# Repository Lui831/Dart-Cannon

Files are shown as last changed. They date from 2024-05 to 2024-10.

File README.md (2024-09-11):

# *Dart Cannon*

### **Integrantes da Equipe**

- João Vitor Choueri Branco (21.01075-7);
- Luiz Henrique Antoniassi Santos (21.01392-6);
- Pedro Afonso Wirthmann Dian (21.01335-7);
- Vitor Guirão Soller (21.01444-2);

---

### **Descrição do Projeto**

O projeto anual envolveu o desenvolvimento do Dart Cannon, um canhão lançador de projéteis leves com um único grau de liberdade, permitindo o disparo em um plano predefinido, e a integração de um sistema inteligente baseado em uma Raspberry Pi. Equipado com uma WebCam para reconhecimento facial, o sistema identifica rostos registrados e aciona o canhão apenas quando uma correspondência é encontrada. Complementando a automação, um dashboard online foi criado usando a plataforma Ubidots, oferecendo controle remoto do ângulo do Dart Cannon, monitoramento do último rosto identificado e um gatilho virtual para o disparo, proporcionando uma solução inovadora e interativa para o lançamento de projéteis.

Para acessar cada parte do projeto (dividido em semestres), acesse as pastas [Semestre1](https://github.com/Lui831/Dart-Cannon/tree/main/Semestre1) e [Semestre2](https://github.com/Lui831/Dart-Cannon/tree/main/Semestre2).

Grupo

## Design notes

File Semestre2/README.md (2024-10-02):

# Dart Cannon v2.0 - Reconhecimento facial

**Dart Cannon** é o projeto do 2° semestre da disciplina **Microcontroladores e Sistemas Embarcados** (EEN251) do **Instituto Mauá de Tecnologia** (IMT), ministrada pelos professores [Sergio Ribeiro Augusto](https://www.linkedin.com/in/sergio-ribeiro-augusto-258a9ba0/?originalSubdomain=br) e [Rodrigo França](https://www.linkedin.com/in/rodrigo-fran%C3%A7a-847872b1/).<br>
Este repositório é responsável pela parte de IoT da aplicação. A infraestrutura AWS foi configurada manualmente

# Requisitos

| id  | requisito | tipo |
| --- | --- | --- |
| 1 | Utilizar sensores digitais | Técnico |
| 2 | Tirar fotos quando reconhecer rostos | Funcional |
| 3 | Subir as fotos em bucket S3 | Funcional |
| 4 | Comparar rostos com as fotos tiradas | Técnico |
| 5 | Utilizar padrões de comunicação HTTP ou MQTT | Técnico |
| 6 | Comunicar-se com outro dispositivo | Técnico |

# Escopo

O projeto consiste em uma Raspberry Pi conectado ao lançador Dart Cannon previamente desenvolvido. O microcomputador possui uma WebCam responsável por reconhecer rostos, então as imagens são comparadas com rostos previamente registrado e caso o resultado seja positivo, o Dart Cannon atira. Também foi construído um dashboard online via Ubidots, no qual ele possui um controlador do ângulo do Dart Cannon, assim como o registro do último rosto identificado pela câmera, e também um gatilho virtual do canhão.

## Diagrama de blocos

Em uma visão do sistema em alto nível, pode-se compreender seu funcionamento a partir do diagrama de blocos visto abaixo.

Dart_Cannon - Blocos

## Esquemático Elétrico

Baseando-se no diagrama de blocos exposto no último tópico e nas tecnologias utilizadas, foi possível a idealização do esquemático elétrico abaixo.

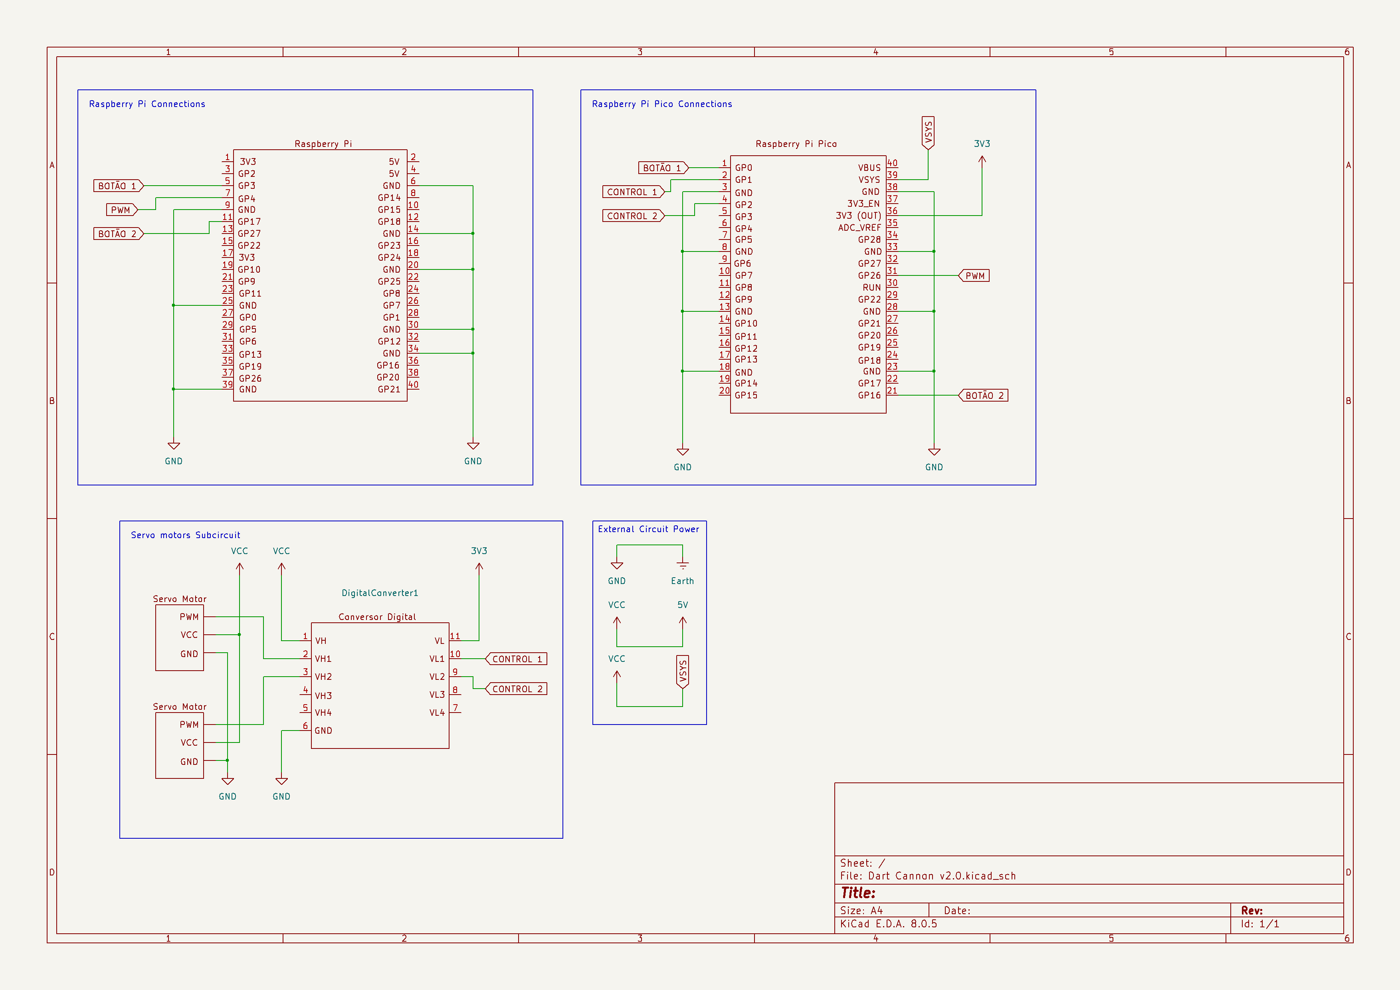
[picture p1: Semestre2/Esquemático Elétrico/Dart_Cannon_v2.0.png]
Dart_Cannon - Blocos


## Tecnologias e conceitos

- AWS
- Requisições HTTP
- Ubidots
- Node-Red
- PIO (Entrada e saída do microprocessador)
- APIs
- Redes

## Materiais

O sistema é montado com os seguintes componentes:

- *Raspberry Pi 3 Model B+* (R$ 385,60);
- *Raspberry* PI Pico (R$ 33,90);
- Servo Motor MG996 (R$ 28,02);
- Servo Motor SG90 (R$ 13,78);
- Filamento PLA para Impressão 3D (R$ 15,00);
    - 100 R$ / filamento de 1 kg, mas o projeto utilizou 150g de filamento
- Mola para acionamento do gatilho (R$ 100,00);
- Placas MDF para base do canhão (R$ 22,00);

Assim, o custo total de implementação do projeto foi de **R$598,30**.

## Modelagem eletrônica

A parte eletrônica do sistema, centralizada essencialmente no Raspberry Pi Pico, foi responsável pelo acionamento de três grandes ações:

- Acionamento manual do canhão, a partir do *dashboard* proveniente do *Ubidots*.
- Acionamento automático do canhão, a partir do reconhecimento visual do ~~REDACTED~~.
- Escolha da angulação do canhão em relação ao eixo do horizonte, com precisão de 9 graus.

Dessa forma, para cada uma das funcionalidades implementadas, os seguintes fluxos de informação foram implementados:

- Para o acionamento manual do canhão, uma estrutura baseada em MQTT foi implementada para a comunicaçao com um botão implementado no *Ubidots*. Essa estrutura foi fundamentada no *Node-RED* e, após realizar a leitura do botão a partir de uma requisição, transfere o seu valor por meio de um sinal digital para o Raspberry Pi Pico, o qual realiza o acionamento do gatilho do canhão.
- Para o acionamento automático do canhão, o funcionamento pode ser considerado análogo ao caso anterior. No entanto, ao invés da determinação do valor de acionamento ser feito a partir da leitura de uma variável no *Ubidots*, esta é realizada por meio do reconhecimento facial (ou não), do ~~REDACTED~~.
- Para a escolha da angulação do canhão, seu funcionamento é também análogo ao seu acionamento manual. No entanto, para a passagem do valor de ângulo do Raspberry Pi para o Raspberry Pi Pico, foi adotada uma transmissão por meio de PWM (o valor do ângulo era linearmente proporcional ao *Duty Cycle* do PWM). Dessa forma, o valor do slider é obtido a partir de uma requisição MQTT por parte do Raspberry Pi a partir do *Node-RED*, dessa forma, este transmite um PWM de valor médio proporcional ao valor do slider, o qual é amostrado pelo Raspberry Pi Pico que efetua a mudança de ângulo do servomotor.

Dessa forma, é possível visualizar as **conexões** realizadas, especialmente entre o Raspberry Pi e Raspberry Pi Pico para a realização das funcionalidades apresentadas, a partir da imagem abaixo.

# Funcionamento

## Funcionamento da Aplicação

**Processo de identificação do rosto**
   - A WebCam fica ativa verificando se existe um rosto detectado;
   - Após 5 segundos, caso ele identifique um rosto novamente, uma foto é tirada e enviada ao _Rekognition_ para validar se tal imagem é parecida o suficiente com o rosto pré-armazenado;
   - Caso o rosto seja parecido, um sinal é enviado ai Raspberry Pi Pico para o disparo do canhão.

**Dashboard Ubidots**
  - Possui um controle deslizante que permite o controle remoto do ângulo do canhão;
  - Possui um botão de disparo do canhão.
  - Possui uma parte referente ao registro da última imagem de rostos reconhecidos pela câmera. Ela é recebida após o upload de uma imagem no _Bucket S3_, a partir de uma _Lambda Function_ acionada como _trigger_ do evento;

## Integração com AWS

arquitetura t3 dart cannon

## Fluxograma do Node-RED Implementado no Raspberry Pi

De forma a complementar o diagrama de blocos exposto anteriormente, é possível especificar as funções e o fluxo de dados para o *Node-RED* a partir da imagem abaixo:

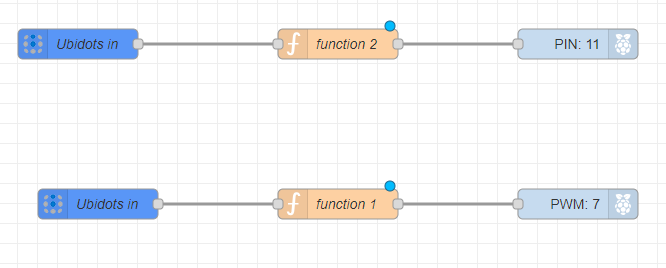
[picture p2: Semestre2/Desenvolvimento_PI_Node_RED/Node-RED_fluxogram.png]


O funcionamento do fluxograma é melhor detalhado na seção anterior, já que é responsável por interfacear diretamente o *dashboard* *Ubidots* e o Raspberry Pi Pico. Para uma melhor compreensão e replicabilidade do fluxograma, é possível obtê-lo diretamente a partir do arquivo `node_red_json.json`, em `./Desenvolvimento_PI_Node_RED`.

## Interface Física a partir do Raspberry Pi Pico

Apresentando seu comportamento descrito na aba "Modelagem Eletrônica", o Raspberry Pi Pico foi responsável por:

- Acionamento do servomotor de "Tiro" a partir do valor digital enviado pelo Raspberry Pi a partir do *Node-RED*.
- Acionamento do servomotor de "Tiro" a partir do valor digital enviado pelo Raspberry Pi a partir do código de reconhecimento facial.
- Controle do ângulo do servomotor de "Angulação" a partir do PWM enviado pelo Raspberry Pi a partir do *Node-RED*.

Para uma melhor visualização de seu funcionamento e operação, é possível encontrar seu código `main.py`, em *Micropython*, na pasta `./Desenvolvimento_PI_Pico`.

# Testes

## Dia 28/08/2024
No dia especificado, fizemos a primeira validação da nossa ideia, utilizando como "cobaia" o professor Sérgio:

https://github.com/user-attachments/assets/659adb91-fa6f-429c-997f-8389b5c48c2b

## Dia 11/09/2024 - Apresentação final

https://github.com/user-attachments/assets/f74fdf56-1614-4386-86fe-6d4188c7c860

## Foto da equipe

Foto da equipe

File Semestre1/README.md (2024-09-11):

# *Dart Cannon v1.0*

### **Descrição Geral**

Repositório para o armazenamento de arquivos, *datasheets*, esquemáticos e códigos referentes ao primeiro projeto semestral da disciplina Microcontroladores e Sistemas Embarcados.

### **Integrantes da Equipe**

- João Vitor Choueri Branco (21.01075-7);
- Luiz Henrique Antoniassi Santos (21.01392-6);
- Pedro Afonso Wirthmann Dian (21.01335-7);
- Vitor Guirão Soller (21.01444-2);

---

### **Descrição do Projeto**

O projeto visa a criação de um canhão lançador de projéteis leves, o *`Dart Cannon`*, o qual teria somente **um** grau de liberdade (atira projéteis somente em um plano pré-determinado) e **calcularia** a trajetória estimada do projeto a ser atirado segundo uma referência específica.

### **Requisitos do Projeto**

Com base em sua descrição simplificada, é possível o levantamento de alguns requisitos necessários para o funcionamento do dispositivo:
1. Desenvolver um canhão capaz de atirar uma bola de ping-pong;
2. Tal canhão deve ter o ângulo em relação ao eixo X controlado pelo usuário;
3. O disparo do canhão deve ser controlado pelo usuário;
4. Deve estimar a altura aproximada da bolinha em relação a um obstáculo a uma distância previamente calculada, exibindo tal valor para o usuário.

### **Lista de Componentes**

- *Raspberry* PI Pico (R$ 33,90);
- Servo Motor MG996 (R$ 28,02);
- Servo Motor SG90 (R$ 13,78);
- Display OLED I²C 128x32 Pixels (R$ 25,42);
- Potenciômetro de 10k ohms (R$ 2,16);
- *Push-button* (R$ 0,19);
- Filamento PLA para Impressão 3D (R$ 15,00);
    - 100 R$ / filamento de 1 kg, mas o projeto utilizou 150g de filamento
- Mola para acionamento do gatilho (R$ 100,00);
- Placas MDF para base do canhão (R$ 22,00);

Assim, o custo total de implementação do projeto foi de **R$ 240,47**.

### **Diagrama de Blocos Lógicos**

Com base nas proposições realizadas, pode-se estruturar o seguinte diagrama que representa a estrutura lógica do *`Dart Cannon`*:

DartCannon

### **Esquema Elétrico**

Esquemático-Completo

### **Modelagem Dinâmica**
 
Para esta parte do projeto, nos baseamos [neste vídeo](https://www.youtube.com/watch?v=1R21wWn0c1s). Fizemos os seguintes rascunhos para entender a ideia inicial da parte mecânica. 

RascunhoMecanico

Após algumas refatorações no modelo, criamos as modelagens 3D a partir do software SOLIDWORKS. Colocamos algumas imagens da Montagem das peças individuais a seguir.

Imagem4

Imagem5

Imagem6

38F3864F-80E2-4926-B548-6E57FF360483

Os modelos utilizados para o projeto foram feitos utilizando o SolidWorks, você pode encontrar o projeto [aqui](https://mauabr-my.sharepoint.com/:u:/g/personal/21_01444-2_maua_br/EdYkC8PgQR5HoR2Ag7gq224BKhw2TkSO_xqjYQnAWDVonw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).
O corpo do lançaddor foi impresso em PLA em uma impressora Creative Ender 3 e foi cortado a Laser, ambas as ferramentas disponíveis no FabLab da Mauá.

### **Organização das Tarefas**

- <u>Organização e implementação do *hardware*</u>: término do esquemático e teste do hardware físico implementado (sem o Raspberry Pi Pico);
- <u>Idealização da arquitetura de *software* e teste</u>: criação de um código em *MicroPython* que garanta o funcionamento integral do canhão. Em primeira instância, os *inputs* seriam compostos principalmente pelo teclado e os *outputs* por *prints*.
- <u>Teste integral de *software* e *hardware*</u>: readaptação do *software* criado para *inputs* e *outputs* do Raspberry Pi Pico, aplicação neste e implementação junto ao *hardware*. Poderão ser testados alguns casos específicos de manuseio do canhão.
- <u>Implementação com parte mecânica e teste final</u>: junção da parte mecânica do projeto com sua parte eletrônica, realizando os testes finais de validação e verificando se a adição de inércia mecânica não interfere no funcionamento dos servo-motores.

## Imagem do Grupo

Grupo

## Vídeo Explicativo

https://github.com/Lui831/Dart-Cannon/assets/81604963/2cd243e0-ed82-4f9d-b0a3-4bb92a8a0a49

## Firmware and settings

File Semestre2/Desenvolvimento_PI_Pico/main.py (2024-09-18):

####################################################################################################################################################
# Título: código main para Dart Cannon (versão mola)
# Descrição: contém manipulação de display I²C, interrupção de botão, manipulação de 2 servo-motores e leitura de potenciômetro
# Autores: João V. C. Branco, Luiz H. A. Santos, Pedro A. W. Dian, Vitor G. Soller
# Data: -
####################################################################################################################################################
# Inclusão de bibliotecas necessárias

from machine import *
from time import *
from servo import *
from math import *


####################################################################################################################################################
# Definição de variáveis globais

# Variáveis relacionadas ao botão - Acionamento Automatico
button_pressed = 0
button_timer = machine.Timer(-1)
push_button = Pin(0, mode = Pin.IN)

# Variáveis relacionadas ao PWM
PWM = Pin(26, Pin.IN)
PWM_timer = machine.Timer(-1)
cont = 0
angle = 0

# Variáveis relacionadas ao botão - Acionamento Manual
button_pressed2 = 0
push_button2 = Pin(16, mode = Pin.IN)


# Variáveis relacionadas aos servo-motores
servo2_timer = machine.Timer(-1)
servo1 = Servo(pin_id = 1)
servo2 = Servo(pin_id = 2)


####################################################################################################################################################
## Definição de funções importantes ao código


# Definição das funções de handler do push_button, timer para a "volta" do servo2 e debounce do push_button

def push_button_handler(pin):
    
    # Definição de variáveis globais
    global servo2
    global servo2_timer
    
    # Ação a ser executada
    servo2.write(110)
    print("BOTÃO APERTADO")

    # Aciona o timer para a voltar para o estado original
    servo2_timer.init(mode=Timer.ONE_SHOT, period=1000, callback=servo2_timer_handler)

def servo2_timer_handler(timer):
    
    # Definição de variáveis globais
    global servo2
    
    # Ação a ser executada
    servo2.write(0)
        
def push_button_check(timer):

    # Definição das variáveis globais
    global push_button
    global button_pressed
    global push_button2
    global button_pressed2

    # Caso o botão esteja apertado...
    if push_button.value() == 1 and button_pressed == 0:
        
        # Faz a ação e seta botão apertado
        push_button_handler(push_button)
        button_pressed = 1
        
    # Caso não esteja apertado...
    elif push_button.value() == 0:
        
        # Reseta o botão apertado
        button_pressed = 0
        
    
    if push_button2.value() == 1 and button_pressed2 == 0:
        
        # Faz a ação e seta botão apertado
        push_button_handler(push_button)
        button_pressed2 = 1
        
    # Caso não esteja apertado...
    elif push_button2.value() == 0:
        
        # Reseta o botão apertado
        button_pressed2 = 0
        
        
# Definição das funções de decodificação do PWM

def inc_counter(timer):
    
    # Definição de variáveis globais
    global cont
    
    # Incrementa o contador com base no valor do pino
    cont += PWM.value()
    
    
def obtain_angle(pin):
    
    # Definição de variáveis globais
    global angle
    global cont
    
    # Calcula o valor do ângulo e insere no motor
    angle = cont * 0.1 * 90
    print(angle)
    servo1.write(angle)
    
    # Reseta o contador
    cont = 0


    
        
####################################################################################################################################################
## Código main


# Definição do timer do botão - Acionamento Automatico e Manual
button_timer.init(period=50, mode=machine.Timer.PERIODIC, callback=push_button_check)

# Definição do timer do PWM
PWM_timer.init(period=100, mode=machine.Timer.PERIODIC, callback=inc_counter)

# Seta a interrupção para reinício da contagem do PWM
PWM.irq(trigger=Pin.IRQ_RISING, handler=obtain_angle)







    

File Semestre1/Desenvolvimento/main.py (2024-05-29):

####################################################################################################################################################
# Título: código main para Dart Cannon (versão mola)
# Descrição: contém manipulação de display I²C, interrupção de botão, manipulação de 2 servo-motores e leitura de potenciômetro
# Autores: João V. C. Branco, Luiz H. A. Santos, Pedro A. W. Dian, Vitor G. Soller
# Data: -
####################################################################################################################################################
# Inclusão de bibliotecas necessárias

from machine import *
from time import *
from servo import *
from ssd1306 import *
from math import *


####################################################################################################################################################
# Definição de variáveis globais

# Variáveis relacionadas ao botão
button_pressed = 0
button_timer = machine.Timer(-1)
push_button = Pin(0, mode = Pin.IN, pull = Pin.PULL_UP)

# Variáveis relacionadas ao potenciômetro
pottentiometer = ADC(26)
pottentiometer_timer = machine.Timer(-1)
pottentiometer_values = []

# Variáveis relacionadas aos servo-motores

servo2_timer = machine.Timer(-1)
servo1 = Servo(pin_id = 1)
servo2 = Servo(pin_id = 2)

# Variáveis relacionadas ao display

i2c0_scl_pin = 17
i2c0_sda_pin = 16
i2c0 = I2C(0, scl=Pin(17), sda=Pin(16), freq=400000)
display = SSD1306_I2C(128, 64, i2c0)
display_timer = machine.Timer(-1)

# Variáveis físicas do teste
Vo = 4.37373
d = 1.9
g = 9.81
deltaH = 0


####################################################################################################################################################
## Definição de funções importantes ao código


# Definição das funções de handler do push_button, timer para a "volta" do servo2 e debounce do push_button

def push_button_handler(pin):
    
    # Definição de variáveis globais
    global servo2
    global servo2_timer
    
    # Ação a ser executada
    servo2.write(110)

    # Aciona o timer para a voltar para o estado original
    servo2_timer.init(mode=Timer.ONE_SHOT, period=1000, callback=servo2_timer_handler)

def servo2_timer_handler(timer):
    
    # Definição de variáveis globais
    global servo2
    
    # Ação a ser executada
    servo2.write(0)
        
def push_button_check(timer):

    # Definição das variáveis globais
    global push_button
    global button_pressed

    # Caso o botão esteja apertado...
    if push_button.value() == 0 and button_pressed == 0:
        
        # Faz a ação e seta botão apertado
        push_button_handler(push_button)
        button_pressed = 1
        
    # Caso não esteja apertado...
    elif push_button.value() == 1:
        
        # Reseta o botão apertado
        button_pressed = 0
        
        
# Definição do handler para a medição do ADC conectado ao potenciômetro
        
def pottentiometer_handler(timer):
    
    global pottentiometer
    global servo1
    global pottentiometer_values
    
    # Insere o valor medido do ADC no início da lista de valores do potenciômetro
    pottentiometer_values.insert(0,pottentiometer.read_u16() * (-90/65535)+90) # pottentiometer.read_u16()*(-90/59500)+90
    print(pottentiometer.read_u16())

    
    # Caso a lista tenha 7 valores, exclui o valor final
    if len(pottentiometer_values) == 7:
        
        del(pottentiometer_values[-1])
        
    # Realiza a média móvel dos últimos valores armazenados na lista    
    pottentiometer_value = sum(pottentiometer_values)/len(pottentiometer_values)
    
    # Aciona o servomotor segundo o valor obtido pela média móvel
    servo1.write(pottentiometer_value)


# Definição do handler relacionado à exibição de deltaH no display

def display_handler(timer):
    
    global pottentiometer
    global deltaH
    global Vo, g, d
    
    # Calculo da variação de altura associada
    pottentiometer_value = sum(pottentiometer_values)/len(pottentiometer_values)
    deltaH = tan(radians(pottentiometer_value)) * d - (g/2) * ((d / (Vo * cos(radians(pottentiometer_value)))))**2
    
    # Caso deltaH seja menor que 0, assume-se variação de 0 metros
    if deltaH < 0:
        
        deltaH = 0
    
    # Reseta o displays
    display.fill(0)
    display.show()
    
    # Escreve o valor calculado de deltaH
    display.text("Angulo: %.1f" % pottentiometer_value, 20, 5)
    display.text("Variacao de", 20, 17)
    display.text("altura calculada:", 8, 29)
    display.text("%.3f" % deltaH, 27, 42)
    display.text("angulo em graus: %.3f" % pottentiometer_value, 20, 5)

    # Atualiza o display
    display.show()
    
        
####################################################################################################################################################
## Código main


# Definição do timer do botão
button_timer.init(period=50, mode=machine.Timer.PERIODIC, callback=push_button_check)

# Definição do timer do potenciômetro
pottentiometer_timer.init(period=200, mode=machine.Timer.PERIODIC, callback=pottentiometer_handler)

# Definição do timer do display
display_timer.init(period=500, mode=machine.Timer.PERIODIC, callback=display_handler)


    

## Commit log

2024-04-03 update(esquemático): adição de esquemático inicial ao repositório
    [Esquemático Elétrico.kicad_pcb, Esquemático Elétrico.kicad_sch]
2024-04-04 addition(esquemático): adição de arquivos do esquemático do projeto e imagem no READ_ME
    [Esquemático Elétrico.kicad_pcb, Esquemático Elétrico.kicad_sch, Projeto_Microcontroladores.kicad_pcb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]
2024-05-30 refat(readme): change project version 🤩
2024-06-02 update(esquemático): schematics correction
    [Projeto_Microcontroladores.kicad_sch]
2024-06-06 refat(readme): add printer, laser cut and some last information
2024-08-27 fix in rasp
    (commited from a rasp)
    [main.py]
2024-08-29 feat(reconhecimento): add another thread in main.py
2024-08-29 fix(reconhecimento): add GPIO functions
    [main.py]
2024-09-04 refat(folders): change folder structure
    [Projeto_Microcontroladores.kicad_pcb, Projeto_Microcontroladores.kicad_sch]
2024-09-04 fix: fix in linux
    [main.py]
2024-09-04 fix(recon): remove threading
2024-09-04 fix(recon): add exit out of if
    [main.py, test.py]
2024-09-11 docs: add videos and images 🔅
2024-09-18 add: addition of project's schematic
2024-09-18 add: addition of raspberry_PI_PICO code
2024-10-02 update: minor modification in schematic
